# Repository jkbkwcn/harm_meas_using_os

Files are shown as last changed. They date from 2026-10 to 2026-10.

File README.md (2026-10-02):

# Sub-LSB Harmonics Measurement System

An electronic circuit project designed to measure mains current harmonics with amplitudes below one Least Significant Bit (LSB) of an Analog-to-Digital Converter.

This project was developed as part of the *Analog Peripheral Circuits in Digital Systems* course at the AGH University of Science and Technology in Kraków.

## Description

The main goal of this project was to design and test an analog-to-digital processing path capable of detecting very weak signals (e.g., 400 µVpp) using a converter with a relatively low base resolution (where 1 LSB ≈ 800 µV). To achieve this, digital signal processing techniques were implemented: oversampling and hardware-based triangular dithering.

The system measures harmonics up to the 5th order (250 Hz) for a 50 Hz mains signal, utilizing an STM32 microcontroller and a dedicated analog signal conditioning circuit on a custom PCB.

## Technologies and Specifications

* Microcontroller: STM32F103C8T6 (ARM Cortex-M3 core)
* ADC: Built-in 12-bit converter
* DSP Methods:
  * Oversampling enabling a theoretical improvement in the Effective Number of Bits (ENOB)
  * Triangular dithering generated via hardware PWM
* Hardware: Custom PCB designed in KiCad, featuring an analog front-end and USB power

## Key Findings and Measurement Results

The system successfully measures signals with amplitudes significantly below the 1 LSB threshold of the converter. Measurements of a 400 µVpp signal (at 50 Hz) yielded consistent results in FFT spectral analysis.

Key observation from the research:
Measurements revealed that the inherent white noise of the ADC and the analog path (amounting to about 2-3 LSB) was already sufficient to act as a natural broadband dither. This intrinsic noise successfully enabled the oversampling process, yielding an ENOB gain of approximately 4 bits. However, due to the ADC's intrinsic noise, the additionally injected triangular dither did not perform as theoretically expected. The built-in white noise essentially overshadowed the triangular signal, negating any extra theoretical benefits the triangle dither would normally provide over white noise. Despite this hardware limitation, the project successfully validated the oversampling concept and fully achieved its measurement objectives.

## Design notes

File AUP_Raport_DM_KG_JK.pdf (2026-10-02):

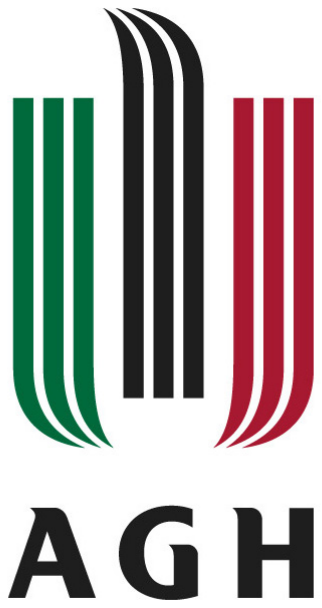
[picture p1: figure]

AKADEMIA GÓRNICZO-HUTNICZA IM. STANISŁAWA STASZICA W KRAKOWIE

WYDZIAŁ INFORMATYKI, ELEKTRONIKI I TELEKOMUNIKACJI

INSTYTUT ELEKTRONIKI

## Układ do pomiaru harmonicznych prądu sieciowego o amplitudach poniżej jednego LSB

założenia, specyfikacja, symulacje, wyniki

Autorzy: | Kacper Gubała, Dawid Maślanka, Jakub Kwiecień
Kierunek studiów: Elektronika i Telekomunikacja, II stopień
Przedmiot: | Analogowe Układy Peryferyjne
Opiekun: | dr hab. inż. Przemysław Krehlik, prof. AGH

Kraków, 2025

## Spis treści

1 Założenia projektowe | 3
2 Symulacje oraz projekt płytki PCB | 4
3 Założenia odnośnie programu oraz układ pomiarowy | 8
4 Wyniki pomiarowe | 10
5 Wnioski | 13

## 1 Założenia projektowe

Celem projektu jest opracowanie układu do pomiaru harmonicznych prądu sieciowego o amplitudach poniżej jednego bitu najmniej znaczącego (LSB) przetwornika analogowo-cyfrowego, z wykorzystaniem techniki nadpróbkowania (oversamplingu) oraz sztucznego ditheringu w postaci sygnału trójkątnego.

### 1.1 Specyfikacja elektryczna

- Napięcie pracy układu: 3.3 V
- Pasmo przenoszenia do: 500 Hz
- Napięcie zasilania: 5 V (USB-C)

### 1.2 Jednostka sterująca

Jednostką sterującą systemu jest mikrokontroler STM32F103C8T6, charakteryzujący się następującymi parametrami:

- Przetwornik ADC o rozdzielczości 12 bitów
- Maksymalny czas konwersji ADC: 1,0 µs
- Obudowa: LQFP, 32 wyprowadzenia
- Moduł PWM: 6 kanałów

### 1.3 Metoda poprawy rozdzielczości

W celu umożliwienia detekcji sygnałów o amplitudzie mniejszej niż jeden LSB przetwornika ADC zastosowano nadpróbkowanie oraz dithering w postaci sygnału trójkątnego. Sygnał trójkątny generowany jest przez moduł PWM mikrokontrolera, a następnie filtrowany do postaci analogowej. Sygnał mierzony jest sumowany z sygnałem trójkątnym o amplitudzie:
Ut = n + 0,5 LSB

gdzie n jest liczbą całkowitą. Okres sygnału trójkątnego jest równy iloczynowi współczynnika nadpróbkowania (OSR) oraz okresu próbkowania przetwornika ADC.

### 1.4 Architektura analogowa

- Sumowanie sygnału mierzonego oraz sygnału ditheringu realizowane jest przy użyciu wzmacniacza operacyjnego w konfiguracji sumatora.
- Zasilanie analogowe realizowane jest z magistrali USB 5 V.
- Stabilizacja napięcia 3,3 V dla mikrokontrolera realizowana jest za pomocą stabilizatora LDO.
- Dla części analogowej przewidziano dodatkową filtrację napięcia zasilania.

### 1.5 Komunikacja i programowanie

- Interfejs komunikacyjny: USB 2.0
- Programowanie i debugowanie mikrokontrolera: złącze SWD

## 2 Symulacje oraz projekt płytki PCB

### 2.1 Symulacja początkowa

- C1 – kondensator separujący składową stałą (sprzęg AC), ponieważ składowa stała sygnału nie jest istotna w kontekście pomiaru. Wartość kondensatora dobrana jest w taki sposób, aby wraz z pozostałymi elementami toru wejściowego częstotliwość odcięcia filtru górnoprzepustowego mieściła się w zakresie 1 ÷ 10 Hz.
- R1 – rezystor zapewniający ustalony potencjał dla kondensatora C1 (zapobiegający „wiszeniu w powietrzu” wejścia). Typowa wartość rezystancji wynosi około 10 kΩ.
- R2 – rezystor pełniący funkcję ograniczenia prądu wejściowego, w szczególności w stanach nieustalonych lub przy przepięciach. Przykładowa wartość rezystancji wynosi około 100 Ω.
- R5, R6 – dzielnik rezystancyjny służący do ustawienia przesunięcia składowej stałej (offsetu DC) sygnału na poziomie połowy napięcia zasilania. Takie rozwiązanie umożliwia wykorzystanie pełnego dynamicznego zakresu przetwornika ADC.
- C2 – kondensator filtrujący napięcie odniesienia offsetu DC. Jego zadaniem jest tłumienie zakłóceń oraz szumów pochodzących z linii zasilania, tak aby nie były one przenoszone na sygnał wejściowy, szczególnie w istotnym paśmie częstotliwości pomiaru.

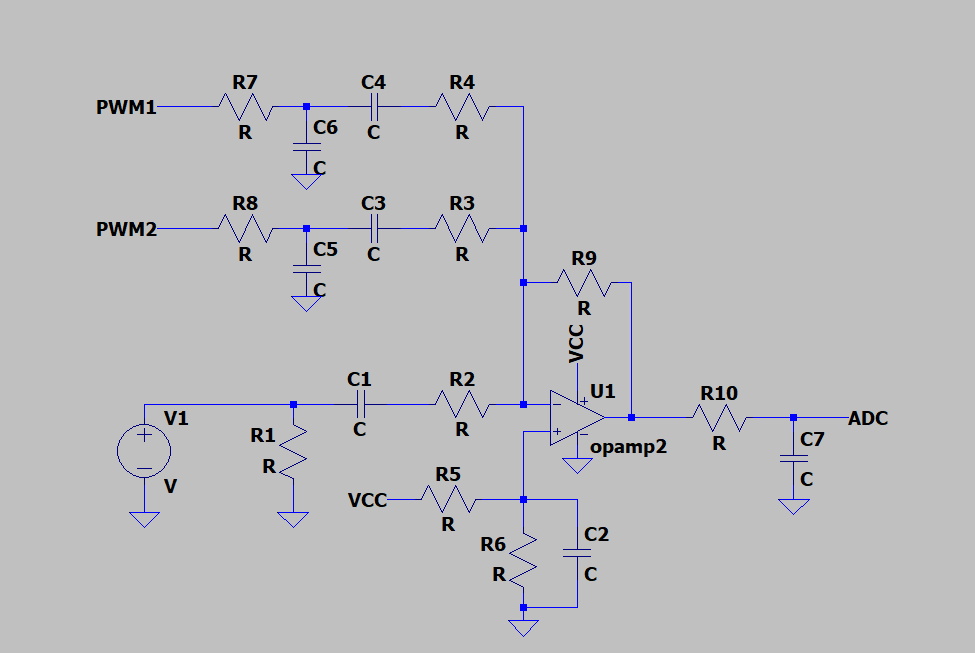
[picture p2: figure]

Rysunek 1: Schemat części analogowej do symulacji

### 2.2 Symulacja końcowa

- Filtr offsetu DC (R5, R6, C2) – parametry filtru zostały dobrane w taki sposób, aby dla częstotliwości sieciowej 50 Hz uzyskać tłumienie rzędu około 30 dB. Dodatkowe ograniczenie zakłóceń w tym paśmie zapewnia zastosowanie stabilizatora LDO o wysokim współczynniku tłumienia tętnień zasilania (PSRR) w zakresie niskich częstotliwości.
- Filtr antyaliasingowy – charakterystyka filtru została ustalona tak, aby dla częstotliwości 500 kHz uzyskać tłumienie w zakresie 40 ÷ 50 dB, natomiast w paśmie użytecznym, w szczególności dla częstotliwości 250 Hz, tłumienie nie przekraczało około 0,01 dB, co zapewnia minimalne zniekształcenia amplitudy sygnału pomiarowego.
- Sprzęganie wejściowe – tor wejściowy został zaprojektowany w taki sposób, aby tłumienie dla częstotliwości 50 Hz wynosiło około 0,01 dB lub nieznacznie więcej, co w praktyce oznacza pomijalny wpływ sprzęgania AC na amplitudę sygnału w paśmie zainteresowania.
- Impedancja wejściowa – wartości rezystorów R1 oraz R2 zostały dobrane tak, aby impedancja wejściowa układu wynosiła około 5 kΩ. Jest to wartość około 100-krotnie większa od impedancji wyjściowej typowego generatora sygnałowego (50 Ω), co minimalizuje wpływ obciążenia na źródło sygnału.

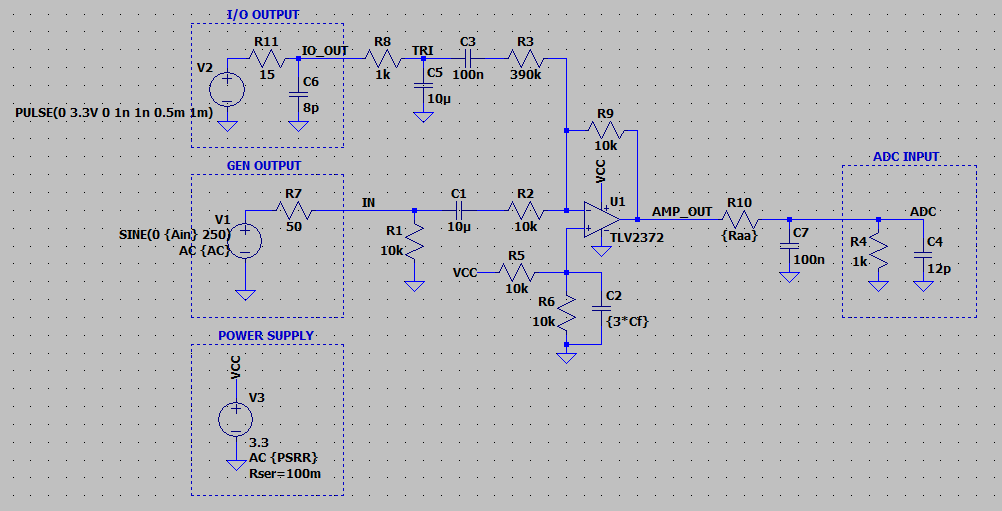
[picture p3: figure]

Rysunek 2: Symulacja filtru antyaliasingowego

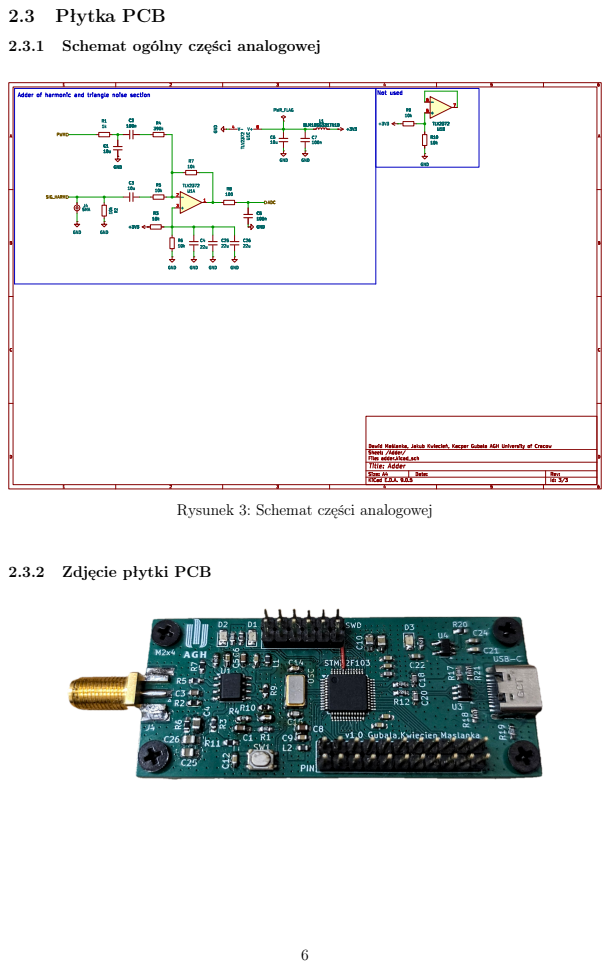
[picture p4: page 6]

2.3.1 Schemat ogólny części analogowej

Title: Adder File: adder.kicadsch Sheet: /Adder/ Dawid Maślanka, Jakub Kwiecień, Kacper Gubała AGH University of Cracow

Rysunek 3: Schemat części analogowej

7NRST 44BOOT0 5PD0 6PD1 2PC13 3PC14 4PC15 18PB0 19PB1 20PB2 39PB3 40PB4 41PB5 42PB6 43PB7 45PB8 46PB9 21PB10 22PB11 25PB12 26PB13 27PB14 28PB15VBAT¹ VDD²⁴³⁶ VSS 23 48 VSSA
PA010 PA111 PA212 PA313 PA414 PA515 PA616 PA717 PA829 PA930 PA1031 PA1132 PA1233 PA1334 PA1437 PA1538

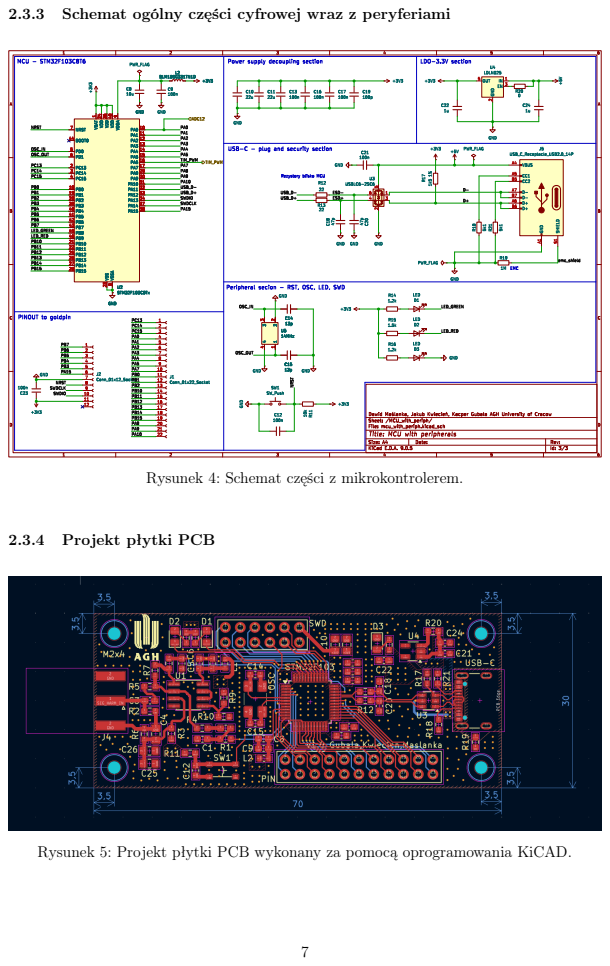
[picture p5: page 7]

Power supply decoupling section

Peripheral secion - RST, OSC, LED, SWD

Title: MCU with peripherals File: mcuwithperiph.kicadsch Sheet: /MCUwithperiph/ Dawid Maślanka, Jakub Kwiecień, Kacper Gubała AGH University of Cracow

Rysunek 4: Schemat części z mikrokontrolerem.

Rysunek 5: Projekt płytki PCB wykonany za pomocą oprogramowania KiCAD.

## 3 Założenia odnośnie programu oraz układ pomiarowy

### 3.1 Analiza przetwornika ADC

Celem analizy jest określenie parametrów pracy przetwornika analogowo-cyfrowego w kontekście pomiaru sygnału sieciowego o częstotliwości 50 Hz oraz jego harmonicznych. Przyjęto założenie, że analizowane będą harmoniczne do maksymalnie piątej włącznie, co odpowiada częstotliwości 250 Hz.
Zgodnie z kryterium Nyquista, aby poprawnie odtworzyć sygnał o częstotliwości 250 Hz, minimalna częstotliwość próbkowania powinna spełniać zależność fs > 500 Hz. W projekcie przyjęto częstotliwość próbkowania z zapasem równą:

fs = 1 kHz.

Zastosowany przetwornik ADC charakteryzuje się rozdzielczością n = 12 bitów oraz maksymalną częstotliwością próbkowania 1 MS/s. Dla zakresu napięć wejściowych 0 ÷ 3 V wartość jednego bitu najmniej znaczącego wynosi w przybliżeniu:

LSB ≈ 800 µV.

W celu zwiększenia efektywnej rozdzielczości przetwornika zastosowano technikę nadpróbkowania. Współczynnik nadpróbkowania (OSR) jest opisany zależnością:

OSR = 2 · 2

p
,

gdzie p oznacza liczbę dodatkowych bitów uzyskanych dzięki oversamplingowi.

Ze względu na ograniczenie maksymalnej częstotliwości próbkowania przetwornika ADC do 1 MHz, przyjęto liczbę dodatkowych bitów p = 7. Daje to współczynnik nadpróbkowania:
OSR = 256.

Przy zadanej częstotliwości próbkowania sygnału użytecznego fs = 1 kHz otrzymano częstotliwość nadpróbkowania:

fos = OSR · fs = 256 kHz.

Zastosowanie nadpróbkowania pozwala na zmniejszenie efektywnej wartości LSB do poziomu:
LSBos ≈ 6,3 µV.

W celu zapewnienia poprawnego działania ditheringu, częstotliwość sygnału trójkątnego została dobrana zgodnie z zależnością:

ftri =

fos
OSR = 1 kHz.

W rzeczywistym układzie obliczone parametry uległy modyfikacji ze względu na częstotliwość zegara kontrolera oraz sposób jego podziału do wyzwalania timerów PWM i timera uruchamiającego zebranie próbki przez konwerter ADC. Częstotliwość timera opisuje wzór:

ftim =

fclk
(P RS + 1) · (ARR + 1),

gdzie PRS to rejestr preskalera, a ARR to Auto Reload Register określający wartość do której zlicza timer.
Mikrokontroler pracował z częstotliwościową fclk = 72 MHz, a nastawy rejestrów przyjeto następująco:
- Timer PWM - P RS = 63, ARR = 1119, co daje częstotliwość:

ftri = 1004, 5 Hz,

- Timer ADC - P RS = 0, ARR = 139, co daje częstotliwość:

ftri = 514, 3 kHz,

która podzielona przez 2 daje częstotliwość próbkowania:

fos = 257, 1 kHz,

### 3.2 Układ pomiarowy

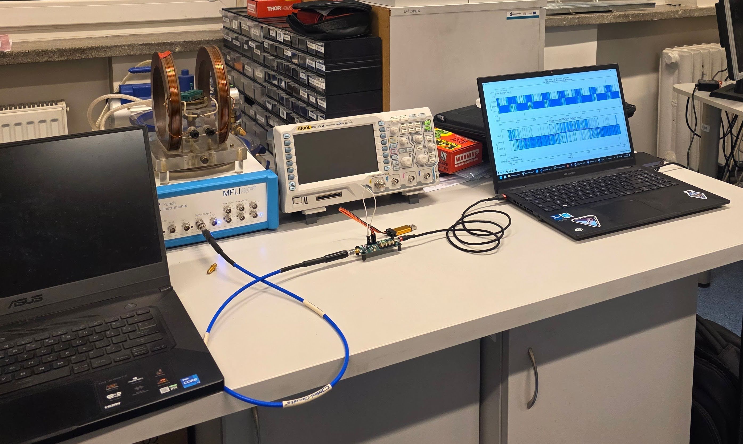
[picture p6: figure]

Rysunek 6: Układ pomiary przy użyciu Lock-Ina jako generatora.

## 4 Wyniki pomiarowe

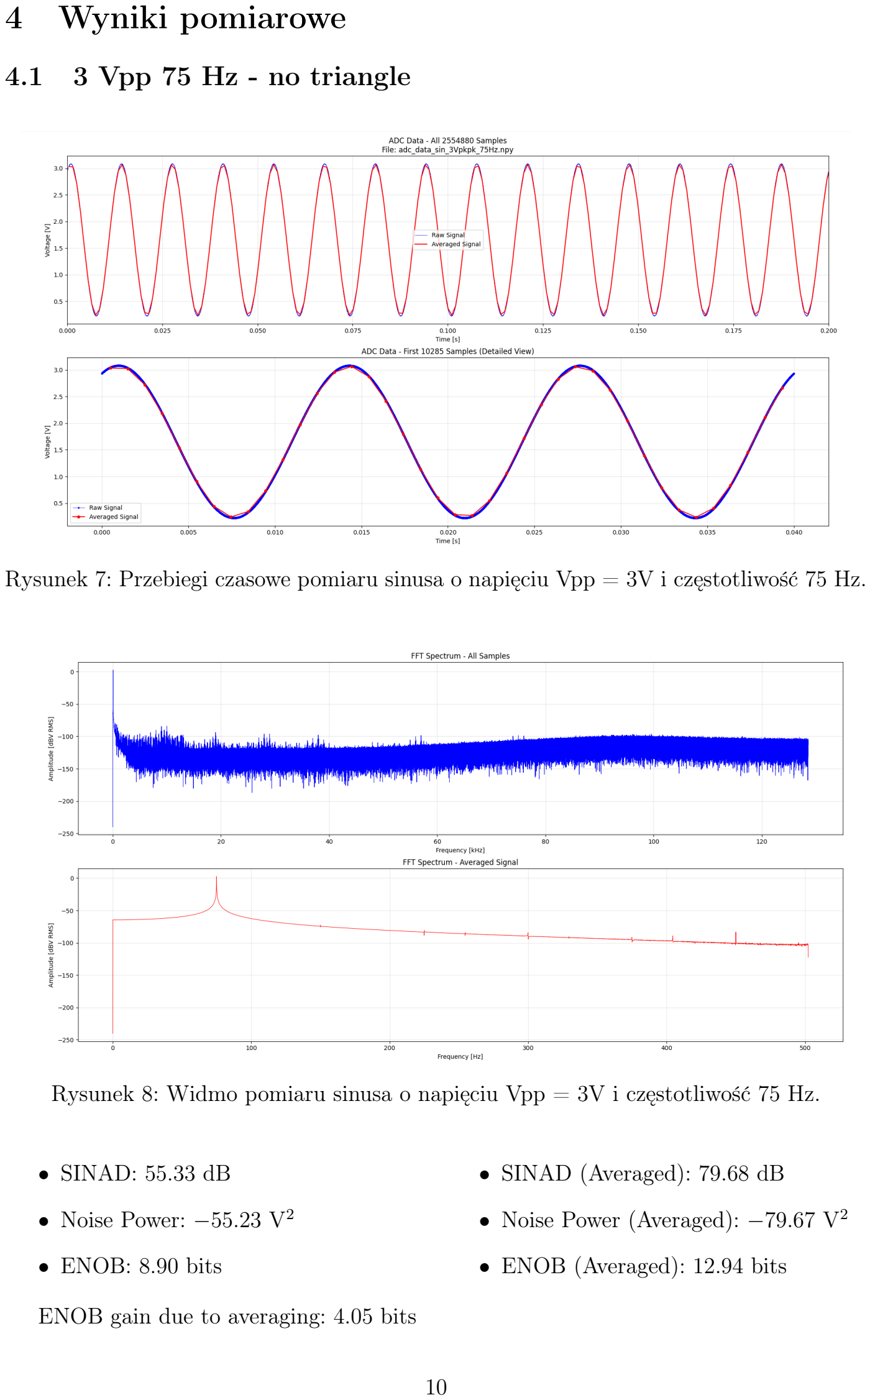
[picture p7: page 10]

4.1 3 Vpp 75 Hz - no triangle

Rysunek 7: Przebiegi czasowe pomiaru sinusa o napięciu Vpp = 3V i częstotliwość 75 Hz.

Rysunek 8: Widmo pomiaru sinusa o napięciu Vpp = 3V i częstotliwość 75 Hz.

- SINAD: 55.33 dB
- Noise Power: −55.23 V²
- ENOB: 8.90 bits
- SINAD (Averaged): 79.68 dB
- Noise Power (Averaged): −79.67 V²
- ENOB (Averaged): 12.94 bits

ENOB gain due to averaging: 4.05 bits

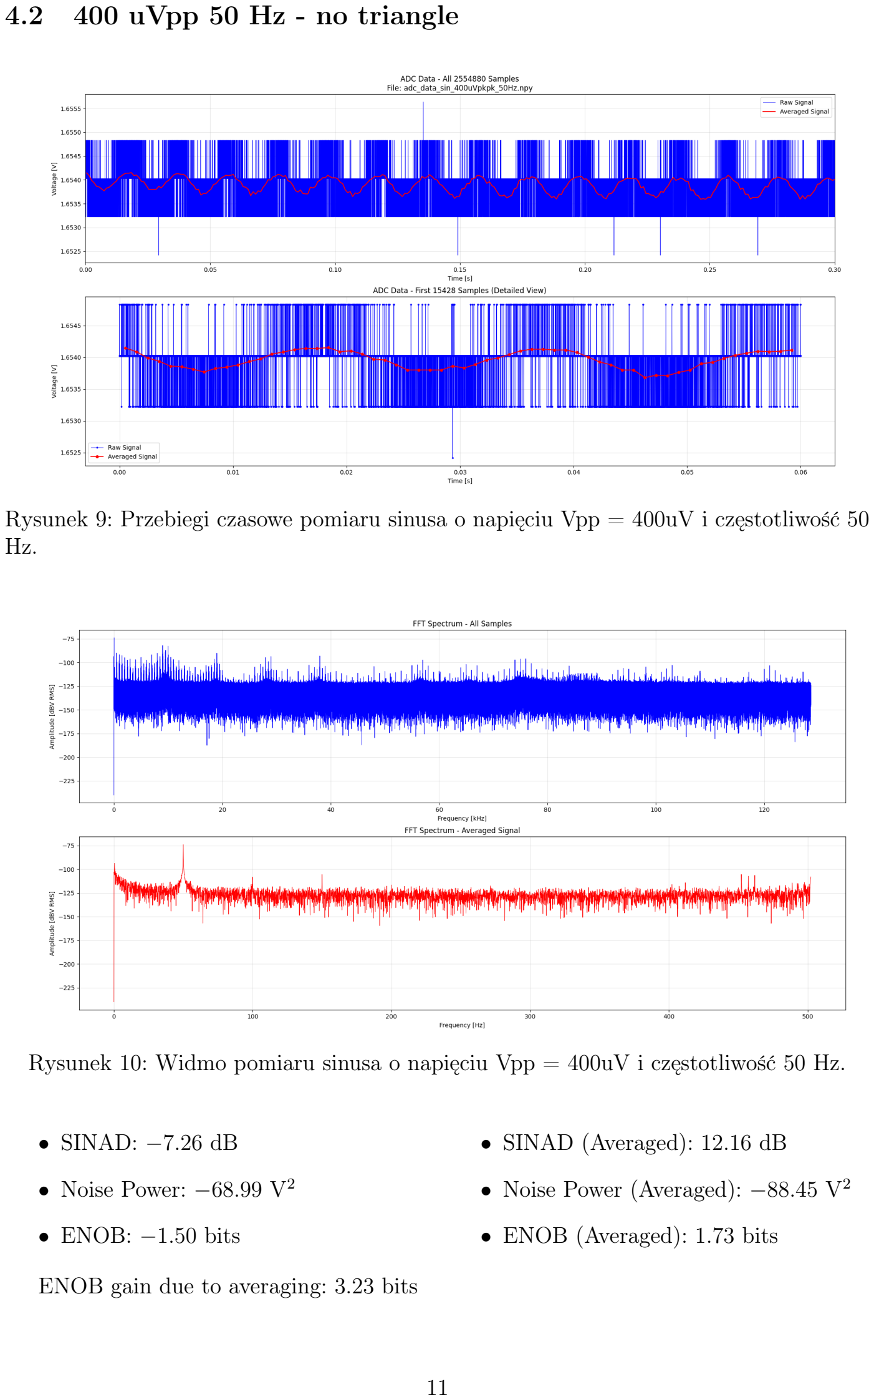
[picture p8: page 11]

4.2 400 uVpp 50 Hz - no triangle

Rysunek 9: Przebiegi czasowe pomiaru sinusa o napięciu Vpp = 400uV i częstotliwość 50 Hz.

Rysunek 10: Widmo pomiaru sinusa o napięciu Vpp = 400uV i częstotliwość 50 Hz.

- SINAD: −7.26 dB
- Noise Power: −68.99 V²
- ENOB: −1.50 bits
- SINAD (Averaged): 12.16 dB
- Noise Power (Averaged): −88.45 V²
- ENOB (Averaged): 1.73 bits

ENOB gain due to averaging: 3.23 bits

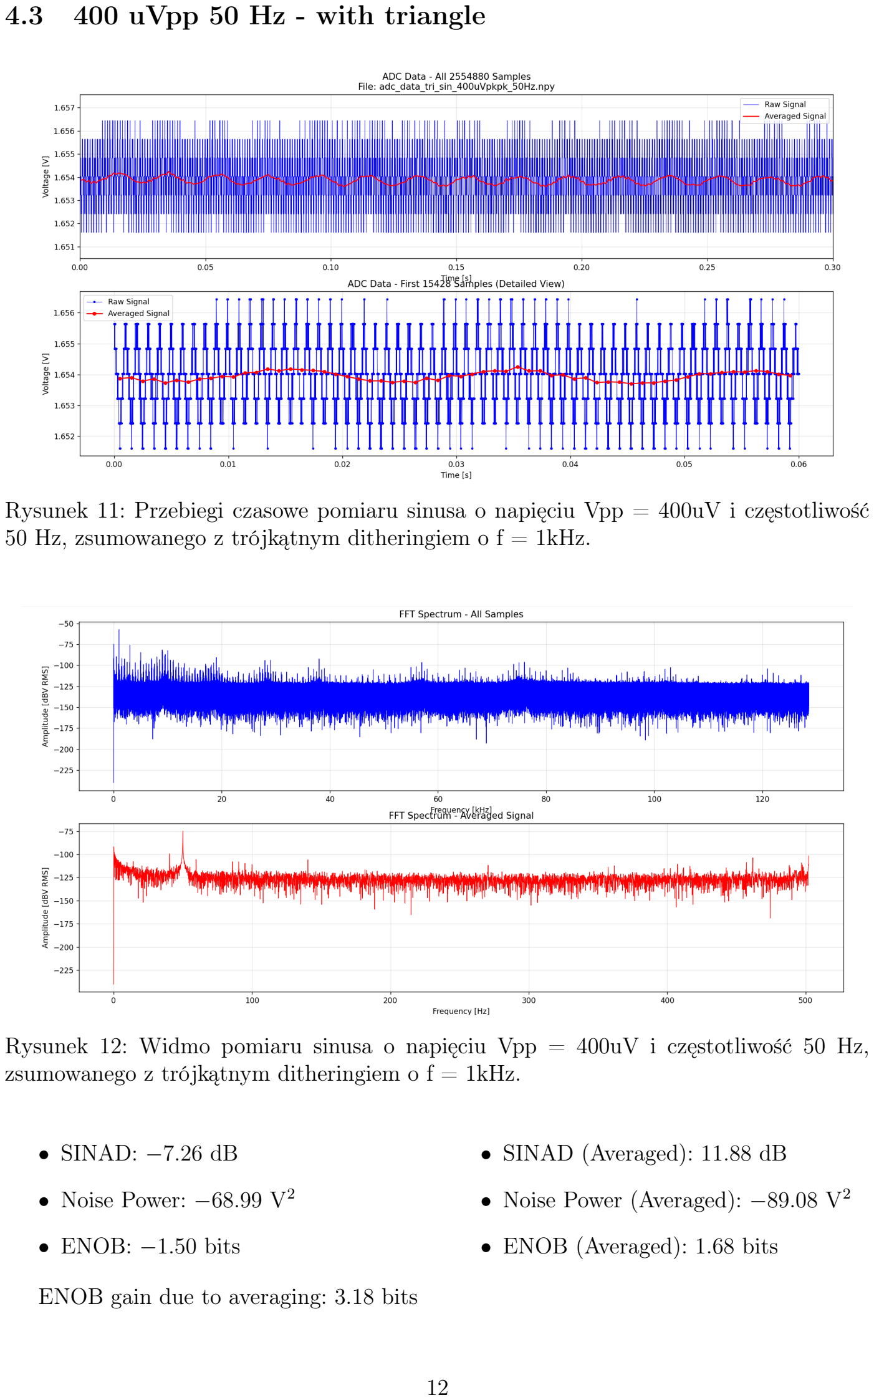
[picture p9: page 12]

4.3 400 uVpp 50 Hz - with triangle

Rysunek 11: Przebiegi czasowe pomiaru sinusa o napięciu Vpp = 400uV i częstotliwość 50 Hz, zsumowanego z trójkątnym ditheringiem o f = 1kHz.

Rysunek 12: Widmo pomiaru sinusa o napięciu Vpp = 400uV i częstotliwość 50 Hz, zsumowanego z trójkątnym ditheringiem o f = 1kHz.

- SINAD: −7.26 dB
- Noise Power: −68.99 V²
- ENOB: −1.50 bits
- SINAD (Averaged): 11.88 dB
- Noise Power (Averaged): −89.08 V²
- ENOB (Averaged): 1.68 bits

ENOB gain due to averaging: 3.18 bits

## 5 Wnioski

Wykonany układ pomiarowy nie do końca spełnił swoje założenia projektowe. Okazało się, że dodanie ditheringu za pomocą sygnału trójkątnego jest zbędne. Sam układ (najpewniej przetwornik ADC) szumi na poziomie 2-3 LSB, co po uśrednieniu daje rezultaty zgodne ze wzorem z noty katalogowej STM. Teoretyczny wzrost parametru ENOB z wykorzystaniem ditheringu w postaci szumu białego wynosi p i jest zgodny ze wzorem:

OSR = 4p

W przypadku badanego układu zysk wynosi 4 bity, co pokrywa się z pomiarem. Dithering sygnałem trójkątnym powinien dać większy zysk; jednak w obecności jakiegokolwiek szumu na najmłodszych bitach nie przynosi dodatkowych efektów.
Finalnie układ pozwala na pomiar sygnałów mniejszych niż pojedynczy LSB z satysfakcjonującym wynikiem oraz zgodną analizą FFT.

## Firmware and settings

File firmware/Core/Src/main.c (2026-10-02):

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
/* Includes ------------------------------------------------------------------*/
#include "main.h"
#include "adc.h"
#include "dma.h"
#include "tim.h"
#include "usb_device.h"
#include "gpio.h"

/* USER CODE BEGIN Includes */
#include "stdio.h"
#include "usbd_cdc_if.h"
#include "usb_device.h"
/* USER CODE END Includes */

/* USER CODE BEGIN PTD */

typedef struct __attribute__((packed))
{
    uint8_t  sync0;
    uint8_t  sync1;
    uint16_t frame_id;
    uint16_t len;
    uint16_t overflow_count;
} frame_hdr_t;

typedef struct
{
    frame_hdr_t hdr;
    uint16_t samples[512];  // ADC_HALF_SAMPLES = 512
} usb_frame_t;

/* USER CODE END PTD */

/* USER CODE BEGIN PD */

#define TIM3_CCR_VALUE 560
#define TIM2_CCR_VALUE 70

#define ADC_BUF_LEN        1024
#define ADC_HALF_SAMPLES   (ADC_BUF_LEN / 2)
#define ADC_HALF_BYTES     (ADC_HALF_SAMPLES * sizeof(uint16_t))

#define NUM_FRAMES         10      // Frame pool size

/* USER CODE END PD */


/* USER CODE BEGIN PV */

uint16_t adc_dma_buf[ADC_BUF_LEN];
usb_frame_t frame_pool[NUM_FRAMES] __attribute__((aligned(4)));

volatile uint8_t frame_wr = 0;
volatile uint8_t frame_rd = 0;
volatile uint16_t frame_id = 0;
volatile uint16_t overflow_count = 0;

/* USER CODE END PV */

void SystemClock_Config(void);
/* USER CODE BEGIN 0 */

void enable_pwm() {
    GPIO_InitTypeDef GPIO_InitStruct = {0};
    GPIO_InitStruct.Pin = GPIO_PIN_6;
    GPIO_InitStruct.Speed = GPIO_SPEED_FREQ_LOW;

    if (HAL_GPIO_ReadPin(TRIGGER_IN_GPIO_Port, TRIGGER_IN_Pin) == GPIO_PIN_SET) {
    	// PWM ON
        GPIO_InitStruct.Mode = GPIO_MODE_AF_PP;
        HAL_GPIO_Init(GPIOA, &GPIO_InitStruct);
        HAL_GPIO_WritePin(LED_RED_GPIO_Port, LED_RED_Pin, GPIO_PIN_SET);
        HAL_GPIO_WritePin(LED_GREEN_GPIO_Port, LED_GREEN_Pin, GPIO_PIN_RESET);
    } else {
    	// PWM OFF
        GPIO_InitStruct.Mode = GPIO_MODE_OUTPUT_PP;
        HAL_GPIO_Init(GPIOA, &GPIO_InitStruct);
        HAL_GPIO_WritePin(GPIOA, GPIO_PIN_6, GPIO_PIN_RESET);
        HAL_GPIO_WritePin(LED_RED_GPIO_Port, LED_RED_Pin, GPIO_PIN_RESET);
        HAL_GPIO_WritePin(LED_GREEN_GPIO_Port, LED_GREEN_Pin, GPIO_PIN_SET);
    }
}

void HAL_GPIO_EXTI_Callback(uint16_t GPIO_Pin) {
    if (GPIO_Pin == TRIGGER_IN_Pin) {
    	enable_pwm();
    }
}

static void Push_ADC_Frame(uint16_t *src)
{
    uint8_t next = (frame_wr + 1) % NUM_FRAMES;

    if (next == frame_rd)
    {
        overflow_count++;
        return; // Buffer full - drop frame
    }

    usb_frame_t *f = &frame_pool[frame_wr];

    // Fill header
    f->hdr.sync0 = 0xA5;
    f->hdr.sync1 = 0x5A;
    f->hdr.frame_id = frame_id++;
    f->hdr.len = ADC_HALF_BYTES;
    f->hdr.overflow_count = overflow_count;

    // Copy ADC data
    memcpy(f->samples, src, ADC_HALF_BYTES);

    // Commit frame
    frame_wr = next;
}

void HAL_ADC_ConvHalfCpltCallback(ADC_HandleTypeDef *hadc)
{
    Push_ADC_Frame(&adc_dma_buf[0]);
}

void HAL_ADC_ConvCpltCallback(ADC_HandleTypeDef *hadc)
{
    Push_ADC_Frame(&adc_dma_buf[ADC_HALF_SAMPLES]);
}

void USB_Task(void)
{
    if (frame_rd == frame_wr)
        return; // No frames to send

    USBD_CDC_HandleTypeDef *hcdc =
        (USBD_CDC_HandleTypeDef *)hUsbDeviceFS.pClassData;

    if (hcdc == NULL || hcdc->TxState != 0)
        return; // USB busy

    if (CDC_Transmit_FS((uint8_t *)&frame_pool[frame_rd], sizeof(usb_frame_t)) == USBD_OK)
    {
        frame_rd = (frame_rd + 1) % NUM_FRAMES;
    }
}

/* USER CODE END 0 */

/**
  * @brief  The application entry point.
  * @retval int
  */
int main(void)
{

  /* MCU Configuration--------------------------------------------------------*/

  /* Reset of all peripherals, Initializes the Flash interface and the Systick. */
  HAL_Init();

  /* Configure the system clock */
  SystemClock_Config();

  /* Initialize all configured peripherals */
  MX_GPIO_Init();
  MX_DMA_Init();
  MX_TIM3_Init();
  MX_USB_DEVICE_Init();
  MX_ADC1_Init();
  MX_TIM2_Init();
  /* USER CODE BEGIN 2 */

  HAL_ADCEx_Calibration_Start(&hadc1);

  HAL_GPIO_WritePin(OUT_GND_GPIO_Port, OUT_GND_Pin, GPIO_PIN_RESET);
  HAL_GPIO_WritePin(OUT_PWR_GPIO_Port, OUT_PWR_Pin, GPIO_PIN_SET);

  __HAL_TIM_SET_COMPARE(&htim3, TIM_CHANNEL_1, TIM3_CCR_VALUE);
  HAL_TIM_PWM_Start(&htim3, TIM_CHANNEL_1);

  __HAL_TIM_SET_COMPARE(&htim2, TIM_CHANNEL_2, TIM2_CCR_VALUE);
  HAL_TIM_OC_Start(&htim2, TIM_CHANNEL_2);

  HAL_ADC_Start_DMA(&hadc1, (uint32_t*)adc_dma_buf, ADC_BUF_LEN);

  enable_pwm();
  /* USER CODE END 2 */

  /* Infinite loop */
  /* USER CODE BEGIN WHILE */
  while (1)
  {
    /* USER CODE END WHILE */

    /* USER CODE BEGIN 3 */
//	  USB_Send_Test_Frame();
//	  HAL_Delay(1);
	  USB_Task();
  }
  /* USER CODE END 3 */
}

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


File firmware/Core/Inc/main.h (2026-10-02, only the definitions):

#define OUT_PWR_Pin GPIO_PIN_5
#define OUT_PWR_GPIO_Port GPIOB
#define OUT_GND_Pin GPIO_PIN_6
#define OUT_GND_GPIO_Port GPIOB
#define TRIGGER_IN_Pin GPIO_PIN_7
#define TRIGGER_IN_GPIO_Port GPIOB
#define TRIGGER_IN_EXTI_IRQn EXTI9_5_IRQn
#define LED_GREEN_Pin GPIO_PIN_8
#define LED_GREEN_GPIO_Port GPIOB
#define LED_RED_Pin GPIO_PIN_9
#define LED_RED_GPIO_Port GPIOB

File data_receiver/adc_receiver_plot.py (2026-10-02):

#!/usr/bin/env python3
"""
ADC Frame Receiver with Auto-Disconnect and Plotting
Receives a specified number of frames, disconnects, and plots the data.
"""

import serial
import struct
import time
import numpy as np
import matplotlib.pyplot as plt
from dataclasses import dataclass
from typing import Optional


@dataclass
class FrameHeader:
    """Frame header structure matching STM32 frame_hdr_t"""

    sync0: int
    sync1: int
    frame_id: int
    length: int
    overflow_count: int


class FrameReceiver:
    """Handles frame reception and loss detection"""

    SYNC_BYTE_0 = 0xA5
    SYNC_BYTE_1 = 0x5A
    HEADER_SIZE = 8  # sync0 + sync1 + frame_id + len + overflow_count

    def __init__(self, port: str, baudrate: int = 115200, timeout: float = 1.0):
        """
        Initialize frame receiver

        Args:
            port: Serial port (e.g., 'COM3' on Windows, '/dev/ttyACM0' on Linux)
            baudrate: Baud rate (default 115200)
            timeout: Read timeout in seconds
        """
        self.ser = serial.Serial(port, baudrate, timeout=timeout)
        self.expected_frame_id: Optional[int] = None
        self.last_overflow_count: Optional[int] = None

        # Statistics
        self.total_frames_received = 0
        self.total_frames_expected = 0
        self.total_dropped = 0
        self.sync_errors = 0
        self.start_time = time.time()

    def find_sync(self) -> bool:
        """
        Search for sync bytes in stream

        Returns:
            True if sync found, False on timeout
        """
        while True:
            b = self.ser.read(1)
            if len(b) == 0:
                return False  # Timeout

            if b[0] == self.SYNC_BYTE_0:
                b2 = self.ser.read(1)
                if len(b2) == 0:
                    return False

                if b2[0] == self.SYNC_BYTE_1:
                    return True

        return False

    def receive_frame(self) -> Optional[tuple[FrameHeader, np.ndarray]]:
        """
        Receive one complete frame

        Returns:
            Tuple of (FrameHeader, ADC samples) or None on error
        """
        # Find sync bytes
        if not self.find_sync():
            return None

        # Read header (without sync bytes)
        header_data = self.ser.read(6)  # frame_id + len + overflow_count
        if len(header_data) != 6:
            self.sync_errors += 1
            return None

        frame_id, data_len, overflow_count = struct.unpack("<HHH", header_data)

        # Validate data length
        if data_len > 4096:  # Sanity check
            self.sync_errors += 1
            return None

        # Read ADC data
        adc_data = self.ser.read(data_len)
        if len(adc_data) != data_len:
            self.sync_errors += 1
            return None

        # Create header object
        header = FrameHeader(sync0=self.SYNC_BYTE_0, sync1=self.SYNC_BYTE_1, frame_id=frame_id, length=data_len, overflow_count=overflow_count)

        # Convert to ADC samples
        num_samples = data_len // 2
        samples = np.frombuffer(adc_data, dtype=np.uint16, count=num_samples)

        # Check for frame loss
        self._check_frame_loss(header)

        # Update statistics
        self.total_frames_received += 1
        self.total_frames_expected += 1

        return header, samples

    def _check_frame_loss(self, header: FrameHeader):
        """Check for dropped frames using frame_id and overflow_count"""

        # Check frame_id sequence
        if self.expected_frame_id is not None:
            expected = self.expected_frame_id

            if header.frame_id != expected:
                # Calculate gap (handle uint16 wraparound)
                if header.frame_id > expected:
                    gap = header.frame_id - expected
                else:
                    gap = (0xFFFF - expected) + header.frame_id + 1

                self.total_dropped += gap
                self.total_frames_expected += gap

                elapsed = time.time() - self.start_time
                print(f"\n⚠️  [{elapsed:.1f}s] FRAME LOSS DETECTED!")
                print(f"    Expected frame_id: {expected}")
                print(f"    Received frame_id: {header.frame_id}")
                print(f"    Gap: {gap} frame(s)")

        # Check MCU overflow counter
        if self.last_overflow_count is not None:
            if header.overflow_count > self.last_overflow_count:
                new_overflows = header.overflow_count - self.last_overflow_count
                elapsed = time.time() - self.start_time
                print(f"\n⚠️  [{elapsed:.1f}s] MCU OVERFLOW!")
                print(f"    MCU dropped {new_overflows} frame(s)")
                print(f"    Total MCU overflows: {header.overflow_count}")

        # Update expected values
        self.expected_frame_id = (header.frame_id + 1) & 0xFFFF
        self.last_overflow_count = header.overflow_count

    def get_stats(self) -> dict:
        """
        Get reception statistics

        Returns:
            Dictionary with statistics
        """
        elapsed = time.time() - self.start_time

        if self.total_frames_expected == 0:
            loss_rate = 0.0
        else:
            loss_rate = (self.total_dropped / self.total_frames_expected) * 100

        if elapsed > 0:
            frame_rate = self.total_frames_received / elapsed
        else:
            frame_rate = 0.0

        return {"elapsed_time": elapsed, "frames_received": self.total_frames_received, "frames_dropped": self.total_dropped, "loss_rate": loss_rate, "frame_rate": frame_rate, "sync_errors": self.sync_errors}

    def print_stats(self):
        """Print formatted statistics"""
        stats = self.get_stats()

        print(f"\n{'='*60}")
        print(f"Reception Statistics")
        print(f"{'='*60}")
        print(f"Elapsed time:      {stats['elapsed_time']:.1f} s")
        print(f"Frames received:   {stats['frames_received']}")
        print(f"Frames dropped:    {stats['frames_dropped']}")
        print(f"Loss rate:         {stats['loss_rate']:.3f}%")
        print(f"Frame rate:        {stats['frame_rate']:.1f} frames/s")
        print(f"Sync errors:       {stats['sync_errors']}")
        print(f"{'='*60}\n")

    def close(self):
        """Close serial port"""
        self.ser.close()
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

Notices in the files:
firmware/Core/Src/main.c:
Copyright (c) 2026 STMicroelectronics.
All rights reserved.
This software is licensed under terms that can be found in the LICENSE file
